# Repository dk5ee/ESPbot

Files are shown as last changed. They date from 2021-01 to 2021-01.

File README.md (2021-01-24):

# ESPbot
Another ESP32-cam based robot project

The repository contains:

* espcam - kicad footprint and library for ESP32-CAM
* TP5400 - kicad footprint and library for TP5400 and ESOP-8
* espbot - kicad project for a motherboard, clone of https://github.com/c3d2/C3-PR/tree/master/pcb

## Considerations TBD

* 0402 or 0805 or other footprints for resistors - make the pcb easier or make it smaller
* same for capacitors
* also capacitors: MLCC or electrolytics for the microfarad caps
* document the reset logic - does this work as intended?
* footprint for the inductor
* which usb socket?
* maximum pcb dimensions - more squarish or more longish?
* also pcb: where should the camera be located on the the assembly - more in the middle or on a side?
* also pcb: where should the antenna be located? on top, protruding over the edge of the motherboard?
* heat problem: the tp5400 and the esp32 will generate heat
* maybe power the motordriver directly from battery power, if the motor allows that
* consider alternatives to TP4500
* the inverters to save pins eliminate the possibility to do a motor brake

## Differences to C3-PR design

* made with kicad instead of easyeda
* instead of power from a USB powerbank this design uses a TP4500 power management chip
* instead of the dual NPN transistor every transistor is the same mosfet

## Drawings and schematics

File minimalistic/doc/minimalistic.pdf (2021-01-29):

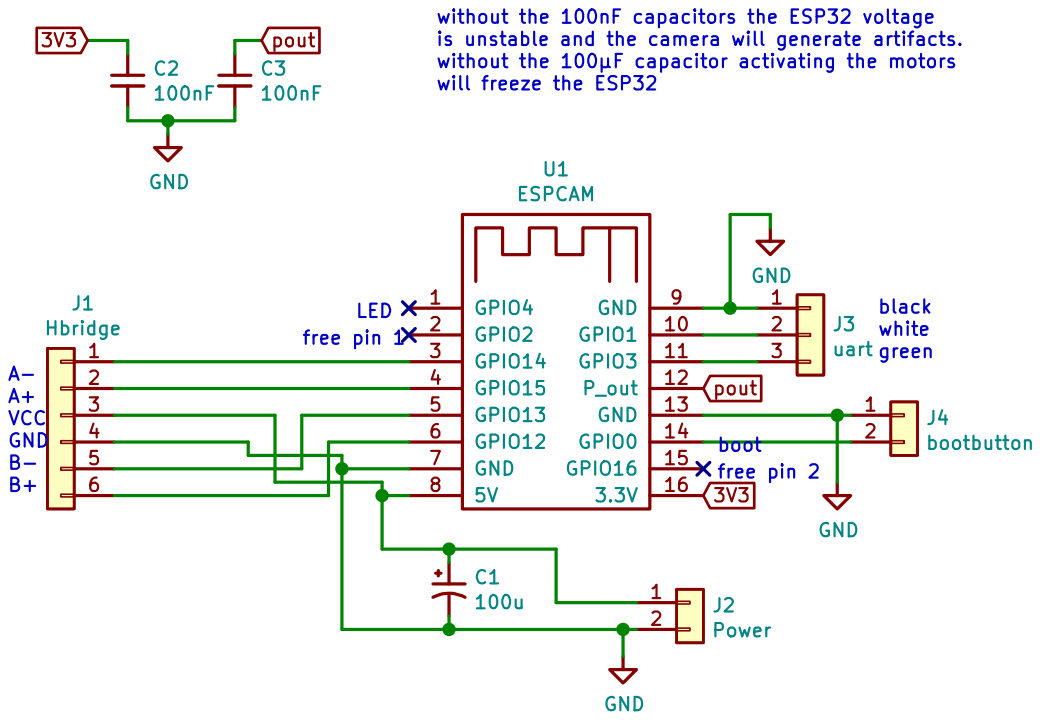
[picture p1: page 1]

is unstable and the camera will generate artifacts.
without the 100µF capacitor activating the motors will freeze the ESP32

Id: 1/1 Title: File: minimalistic.sch Sheet: / GND

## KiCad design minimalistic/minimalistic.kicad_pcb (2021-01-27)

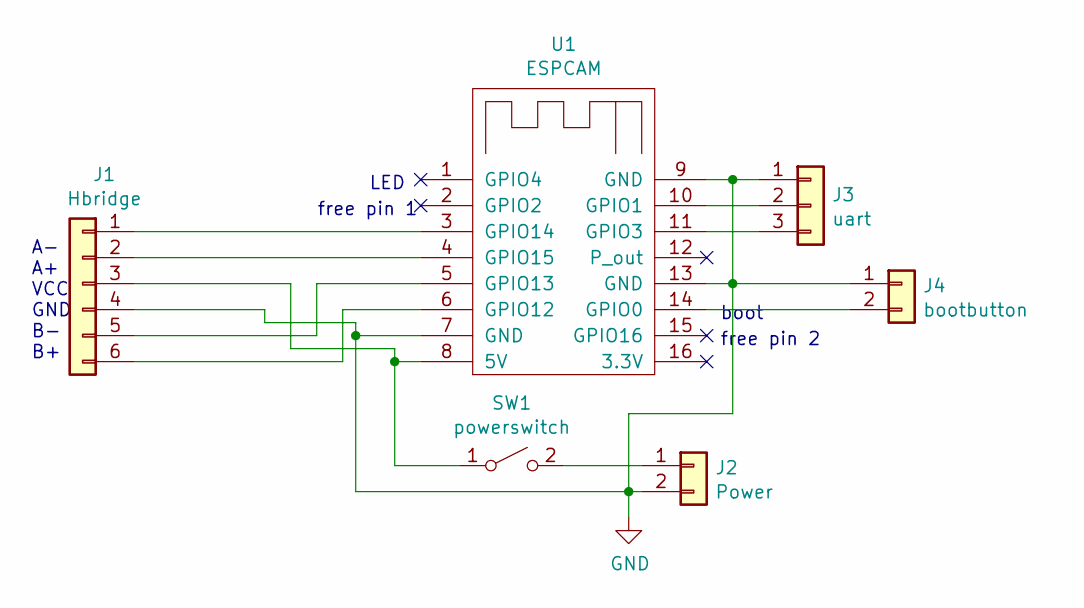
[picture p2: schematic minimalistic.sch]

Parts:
J1: Hbridge; PinHeader_1x06_P2.54mm_Vertical
J2: Power; JST_EH_B2B-EH-A_1x02_P2.50mm_Vertical
J3: uart; PinHeader_1x03_P2.54mm_Vertical
J4: bootbutton; PinHeader_1x02_P2.54mm_Vertical
SW1: powerswitch; PinHeader_1x02_P2.54mm_Vertical
U1: ESPCAM; ESPCAM_bottom

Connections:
GND: J1.4, J2.2, J3.1, J4.1, U1.7 (GND), U1.9 (GND), U1.13 (GND)
unnamed: J1.1, U1.3 (GPIO14)
unnamed: J1.2, U1.4 (GPIO15)
unnamed: J1.3, SW1.1 (A), U1.8 (5V)
unnamed: J1.5, U1.5 (GPIO13)
unnamed: J1.6, U1.6 (GPIO12)
unnamed: J2.1, SW1.2 (B)
unnamed: J3.2, U1.10 (GPIO1)
unnamed: J3.3, U1.11 (GPIO3)
unnamed: J4.2, U1.14 (GPIO0)

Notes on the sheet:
A- A+ VCC GND B- B+
LED
boot
free pin 1
free pin 2

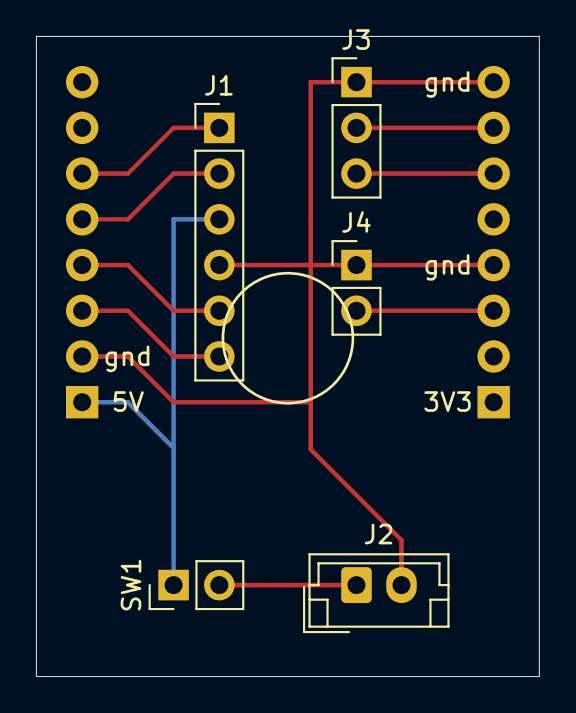
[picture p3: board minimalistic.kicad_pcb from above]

Board: 2 copper layers, 27.9 x 35.6 mm, 6 parts (0 on the bottom side), 10 nets.

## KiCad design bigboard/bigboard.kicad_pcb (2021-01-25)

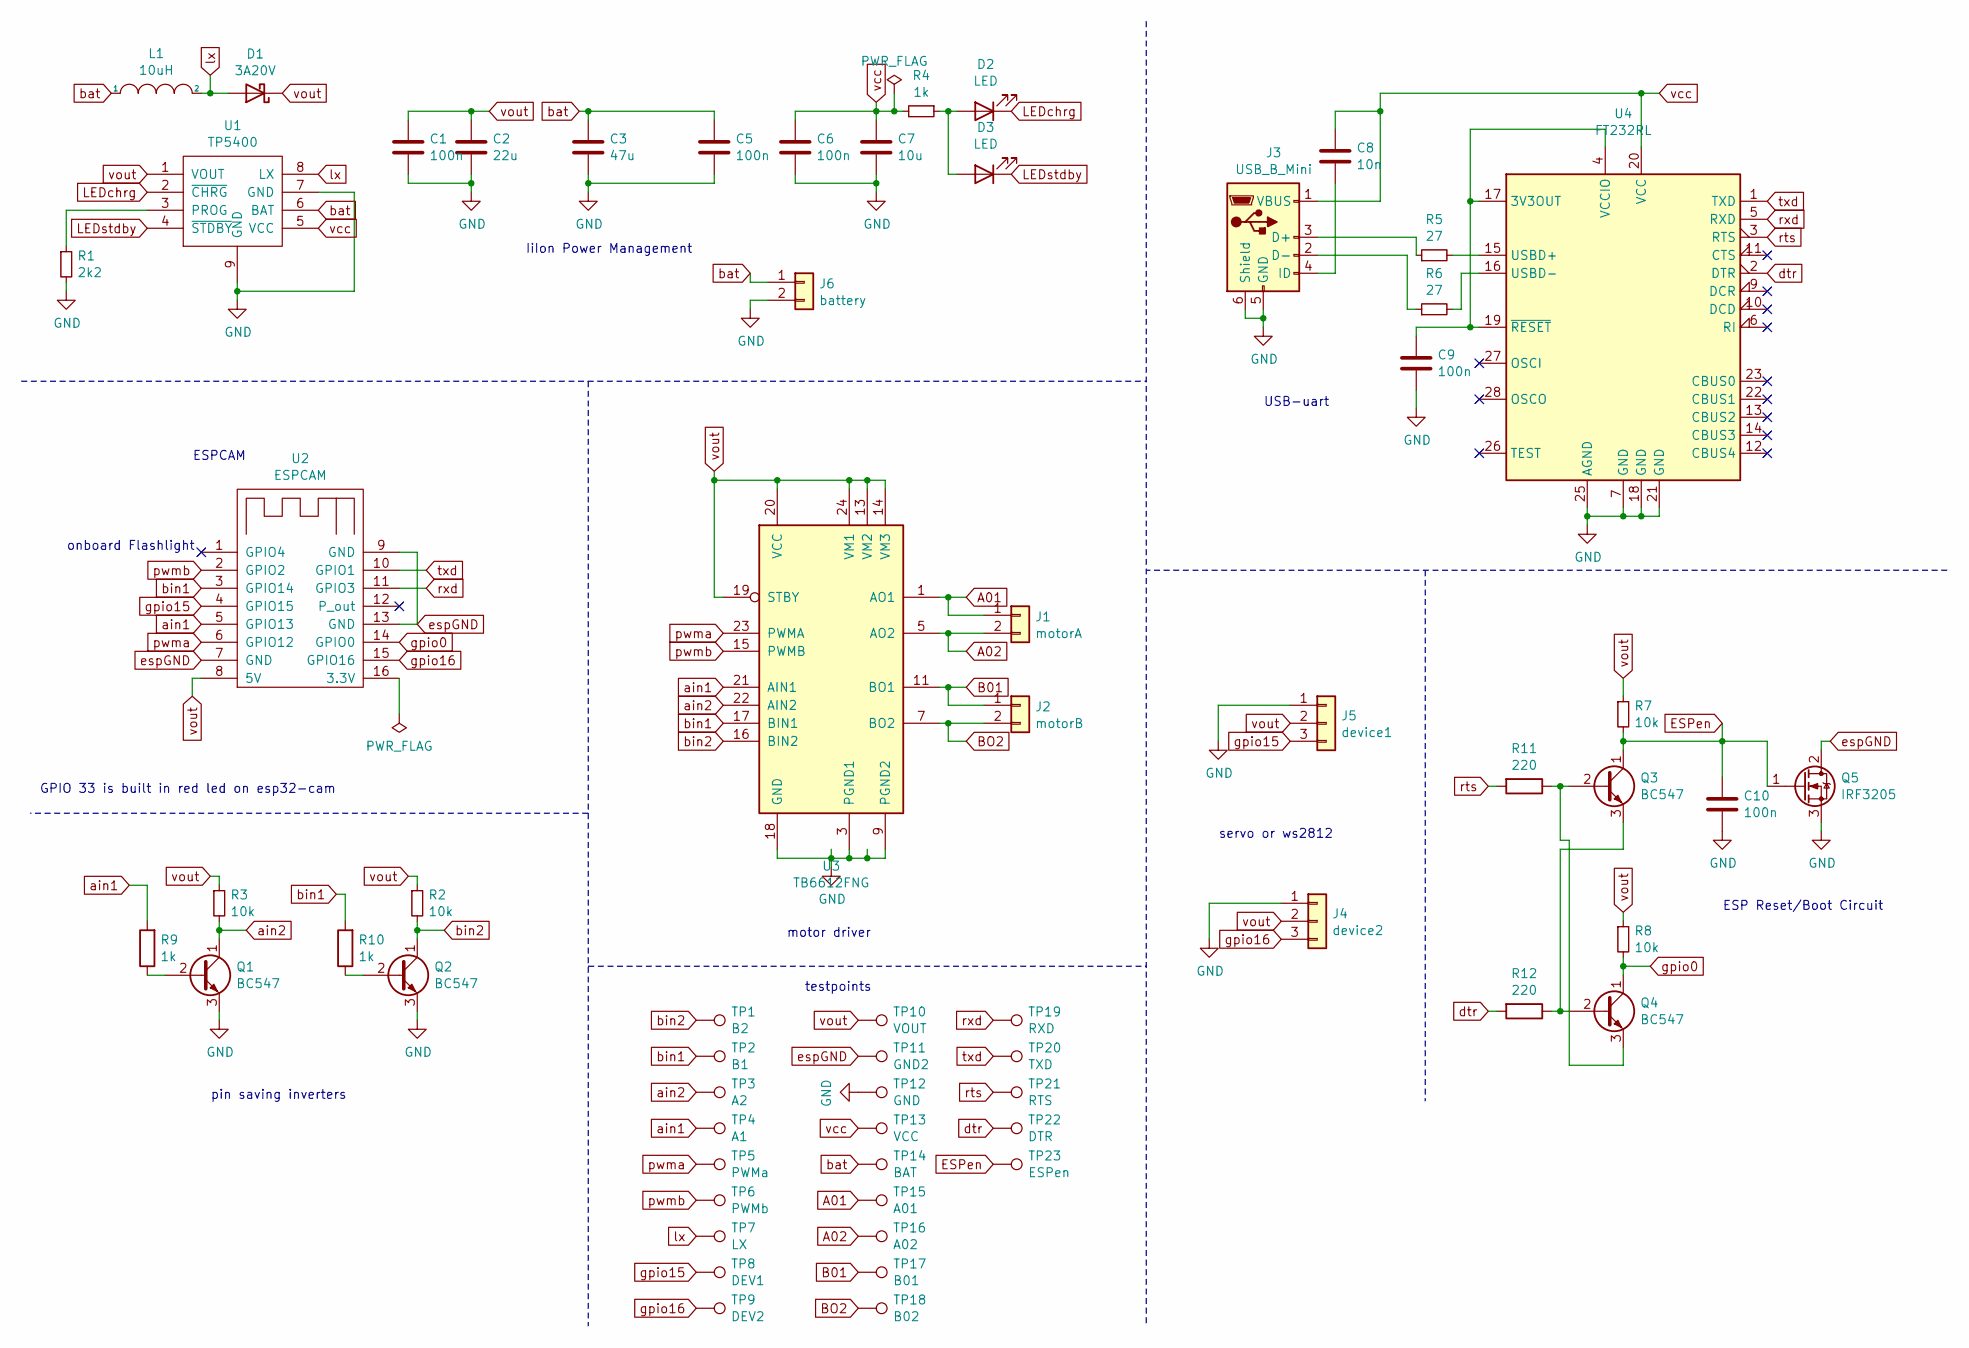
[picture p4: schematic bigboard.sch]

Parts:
C1, C5, C6, C9, C10: 100n; C_Disc_D3.0mm_W1.6mm_P2.50mm
C2: 22u; CP_Radial_D10.0mm_P2.50mm_P5.00mm
C3: 47u; CP_Radial_D10.0mm_P2.50mm_P5.00mm
C7: 10u; CP_Radial_D10.0mm_P2.50mm_P5.00mm
C8: 10n; C_Disc_D4.3mm_W1.9mm_P5.00mm
D1: 3A20V; D_A-405_P7.62mm_Horizontal
D2, D3: LED; LED_D3.0mm
J1: motorA; PinHeader_1x02_P2.54mm_Vertical
J2: motorB; PinHeader_1x02_P2.54mm_Vertical
J3: USB_B_Mini; USB_Micro-B_Amphenol_10118194_Horizontal
J4: device2; PinHeader_1x03_P2.54mm_Vertical
J5: device1; PinHeader_1x03_P2.54mm_Vertical
J6: battery; PinHeader_1x02_P2.54mm_Vertical
L1: 10uH; L_Toroid_Vertical_L10.0mm_W5.0mm_P5.08mm
Q1, Q2, Q3, Q4: BC547; TO-92_Inline
Q5: IRF3205; TO-220F-3_Horizontal_TabDown
R1: 2k2; R_Axial_DIN0204_L3.6mm_D1.6mm_P5.08mm_Horizontal
R2, R3, R7, R8: 10k; R_Axial_DIN0204_L3.6mm_D1.6mm_P5.08mm_Horizontal
R4, R9, R10: 1k; R_Axial_DIN0204_L3.6mm_D1.6mm_P5.08mm_Horizontal
R5, R6: 27; R_Axial_DIN0204_L3.6mm_D1.6mm_P5.08mm_Horizontal
R11, R12: 220; R_Axial_DIN0204_L3.6mm_D1.6mm_P5.08mm_Horizontal
TP1: B2; TestPoint_Bridge_Pitch2.54mm_Drill0.7mm
TP2: B1; TestPoint_Bridge_Pitch2.54mm_Drill0.7mm
TP3: A2; TestPoint_Bridge_Pitch2.54mm_Drill0.7mm
TP4: A1; TestPoint_Bridge_Pitch2.54mm_Drill0.7mm
TP5: PWMa; TestPoint_Bridge_Pitch2.54mm_Drill0.7mm
TP6: PWMb; TestPoint_Bridge_Pitch2.54mm_Drill0.7mm
TP7: LX; TestPoint_Bridge_Pitch2.54mm_Drill0.7mm
TP8: DEV1; TestPoint_Bridge_Pitch2.54mm_Drill0.7mm
TP9: DEV2; TestPoint_Bridge_Pitch2.54mm_Drill0.7mm
TP10: VOUT; TestPoint_Bridge_Pitch2.54mm_Drill0.7mm
TP11: GND2; TestPoint_Bridge_Pitch2.54mm_Drill0.7mm
TP12: GND; TestPoint_Bridge_Pitch2.54mm_Drill0.7mm
TP13: VCC; TestPoint_Bridge_Pitch2.54mm_Drill0.7mm
TP14: BAT; TestPoint_Bridge_Pitch2.54mm_Drill0.7mm
TP15: A01; TestPoint_Bridge_Pitch2.54mm_Drill0.7mm
TP16: A02; TestPoint_Bridge_Pitch2.54mm_Drill0.7mm
TP17: B01; TestPoint_Bridge_Pitch2.54mm_Drill0.7mm
TP18: B02; TestPoint_Bridge_Pitch2.54mm_Drill0.7mm
TP19: RXD; TestPoint_Bridge_Pitch2.54mm_Drill0.7mm
TP20: TXD; TestPoint_Bridge_Pitch2.54mm_Drill0.7mm
TP21: RTS; TestPoint_Bridge_Pitch2.54mm_Drill0.7mm
TP22: DTR; TestPoint_Bridge_Pitch2.54mm_Drill0.7mm
TP23: ESPen; TestPoint_Bridge_Pitch2.54mm_Drill0.7mm
U1: TP5400; ESOP8-F.Cu-only
U2: ESPCAM; ESPCAM_bottom
U3: TB6612FNG; SSOP-24_5.3x8.2mm_P0.65mm
U4: FT232RL; SSOP-28_5.3x10.2mm_P0.65mm

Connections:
A01: J1.1, TP15.1, U3.1 (AO1), U3.2 (AO1)
A02: J1.2, TP16.1, U3.5 (AO2), U3.6 (AO2)
B01: J2.1, TP17.1, U3.11 (BO1), U3.12 (BO1)
BO2: J2.2, TP18.1, U3.7 (BO2), U3.8 (BO2)
ESPen: C10.1, Q3.1 (C), Q5.1 (G), R7.2, TP23.1
GND: C1.2, C2.2, C3.2, C5.2, C6.2, C7.2, C9.2, C10.2, J3.5 (GND), J3.6 (Shield), J4.1, J5.1, J6.2, Q1.3 (E), Q2.3 (E), Q5.3 (S), R1.2, TP12.1, U1.7 (GND), U1.9 (GND), U3.3 (PGND1), U3.4 (PGND1), U3.9 (PGND2), U3.10 (PGND2), U3.18 (GND), U4.7 (GND), U4.18 (GND), U4.21 (GND), U4.25 (AGND)
LEDchrg: D2.1 (K), U1.2 (~CHRG)
LEDstdby: D3.1 (K), U1.4 (~STDBY)
unnamed: C8.2, J3.4 (ID)
unnamed: C9.1, U4.4 (VCCIO), U4.17 (3V3OUT), U4.19 (~RESET~)
unnamed: D2.2 (A), D3.2 (A), R4.1
unnamed: J3.2 (D-), R6.1
unnamed: J3.3 (D+), R5.1
unnamed: Q1.2 (B), R9.1
unnamed: Q2.2 (B), R10.1
unnamed: Q3.2 (B), Q4.3 (E), R11.1
unnamed: Q3.3 (E), Q4.2 (B), R12.1
unnamed: R1.1, U1.3 (PROG)
unnamed: R5.2, U4.15 (USBD+)
unnamed: R6.2, U4.16 (USBD-)
ain1: R9.2, TP4.1, U2.5 (GPIO13), U3.21 (AIN1)
ain2: Q1.1 (C), R3.2, TP3.1, U3.22 (AIN2)
bat: C3.1, C5.1, J6.1, L1.1, TP14.1, U1.6 (BAT)
bin1: R10.2, TP2.1, U2.3 (GPIO14), U3.17 (BIN1)
bin2: Q2.1 (C), R2.2, TP1.1, U3.16 (BIN2)
dtr: R12.2, TP22.1, U4.2 (DTR)
espGND: Q5.2 (D), TP11.1, U2.7 (GND), U2.9 (GND), U2.13 (GND)
gpio0: Q4.1 (C), R8.2, U2.14 (GPIO0)
gpio15: J5.3, TP8.1, U2.4 (GPIO15)
gpio16: J4.3, TP9.1, U2.15 (GPIO16)
lx: D1.2 (A), L1.2, TP7.1, U1.8 (LX)
pwma: TP5.1, U2.6 (GPIO12), U3.23 (PWMA)
pwmb: TP6.1, U2.2 (GPIO2), U3.15 (PWMB)
rts: R11.2, TP21.1, U4.3 (RTS)
rxd: TP19.1, U2.11 (GPIO3), U4.5 (RXD)
txd: TP20.1, U2.10 (GPIO1), U4.1 (TXD)
vcc: C6.1, C7.1, C8.1, J3.1 (VBUS), R4.2, TP13.1, U1.5 (VCC), U4.20 (VCC)
vout: C1.1, C2.1, D1.1 (K), J4.2, J5.2, R2.1, R3.1, R7.1, R8.1, TP10.1, U1.1 (VOUT), U2.8 (5V), U3.13 (VM2), U3.14 (VM3), U3.19 (STBY), U3.20 (VCC), U3.24 (VM1)

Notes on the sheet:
IiIon Power Management
USB-uart
motor driver
ESPCAM
ESP Reset/Boot Circuit
onboard Flashlight
servo or ws2812
pin saving inverters
GPIO 33 is built in red led on esp32-cam
testpoints

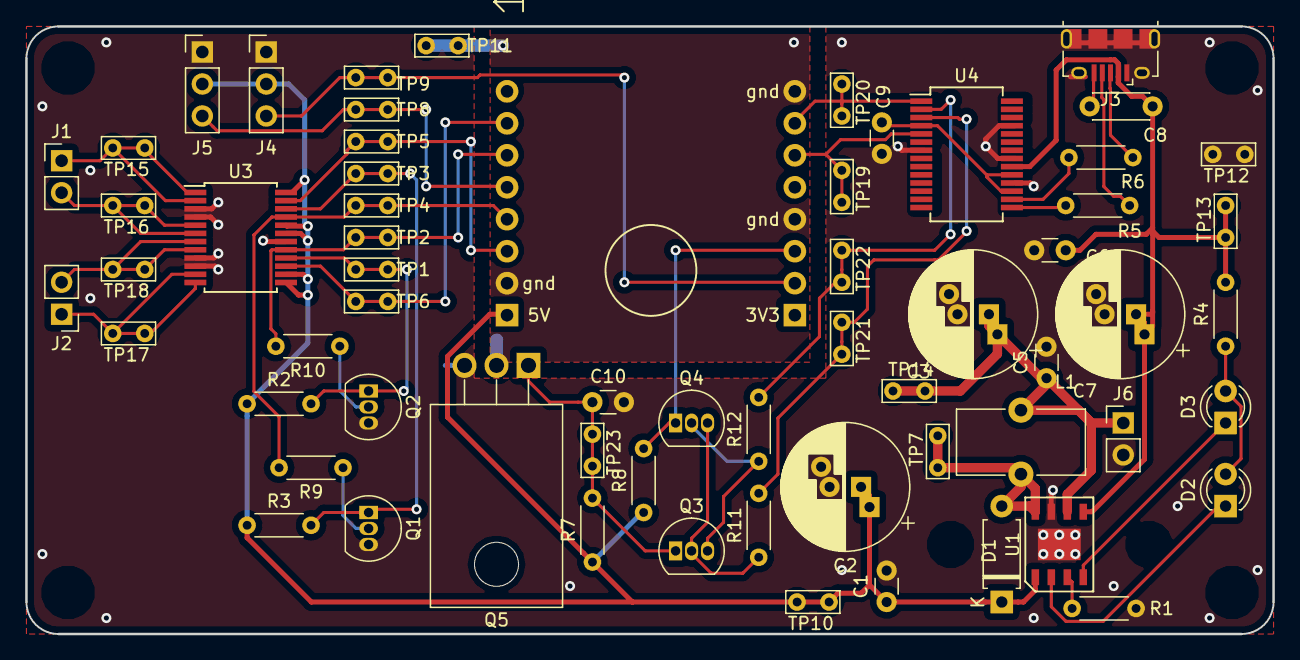
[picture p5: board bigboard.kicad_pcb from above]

Board: 2 copper layers, 99.1 x 48.3 mm, 63 parts (0 on the bottom side), 38 nets.

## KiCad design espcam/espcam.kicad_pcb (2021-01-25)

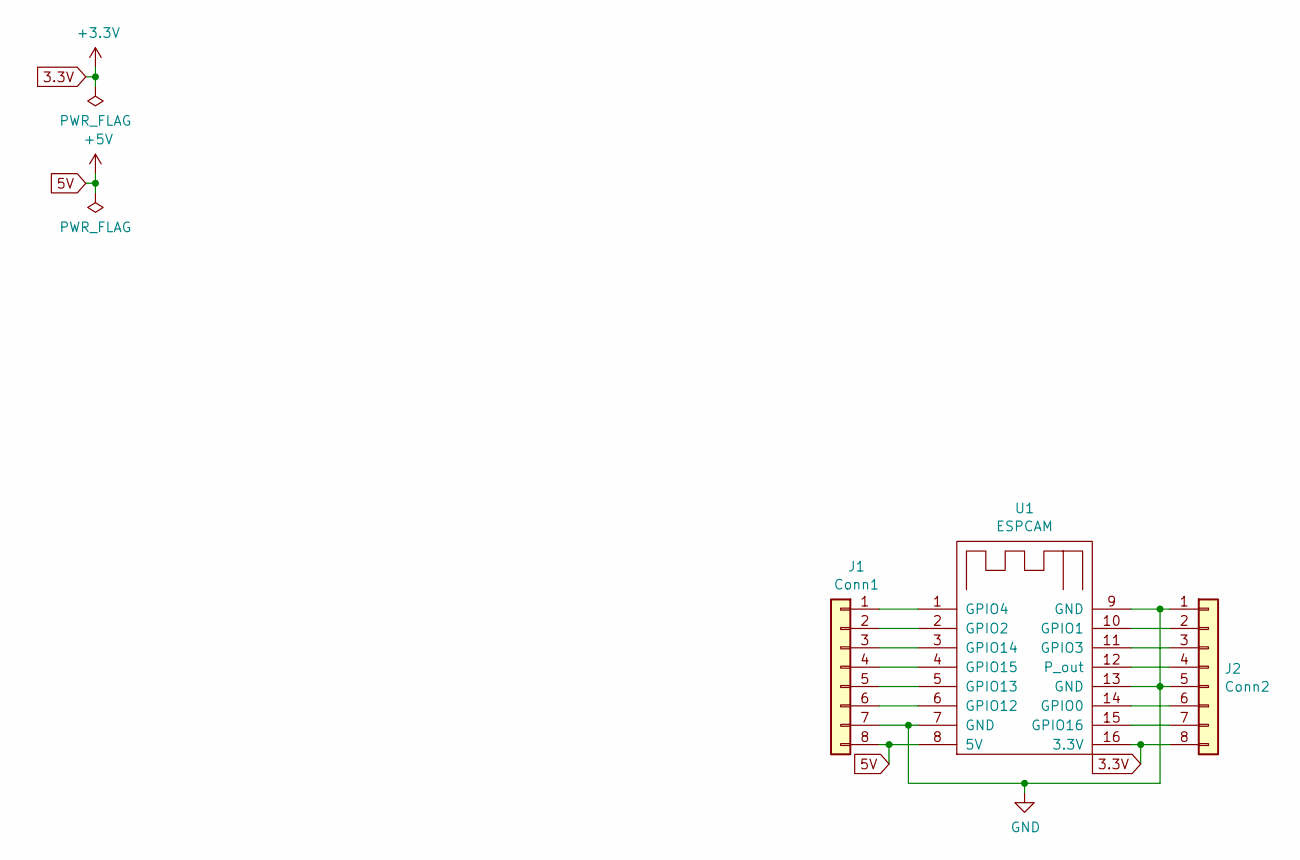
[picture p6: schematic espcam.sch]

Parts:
J1: Conn1; PinSocket_1x08_P2.54mm_Vertical
J2: Conn2; PinSocket_1x08_P2.54mm_Vertical
U1: ESPCAM; ESPCAM_bottom

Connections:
3.3V: J2.8, U1.16 (3.3V)
5V: J1.8, U1.8 (5V)
GND: J1.7, J2.1, J2.5, U1.7 (GND), U1.9 (GND), U1.13 (GND)
unnamed: J1.1, U1.1 (GPIO4)
unnamed: J1.2, U1.2 (GPIO2)
unnamed: J1.3, U1.3 (GPIO14)
unnamed: J1.4, U1.4 (GPIO15)
unnamed: J1.5, U1.5 (GPIO13)
unnamed: J1.6, U1.6 (GPIO12)
unnamed: J2.2, U1.10 (GPIO1)
unnamed: J2.3, U1.11 (GPIO3)
unnamed: J2.4, U1.12 (P_out)
unnamed: J2.6, U1.14 (GPIO0)
unnamed: J2.7, U1.15 (GPIO16)

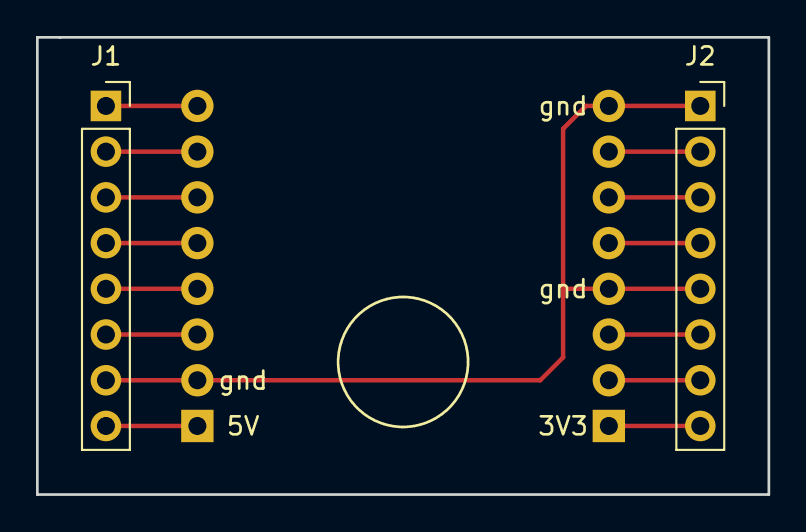
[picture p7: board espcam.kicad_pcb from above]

Board: 2 copper layers, 40.6 x 25.4 mm, 3 parts (0 on the bottom side), 14 nets.

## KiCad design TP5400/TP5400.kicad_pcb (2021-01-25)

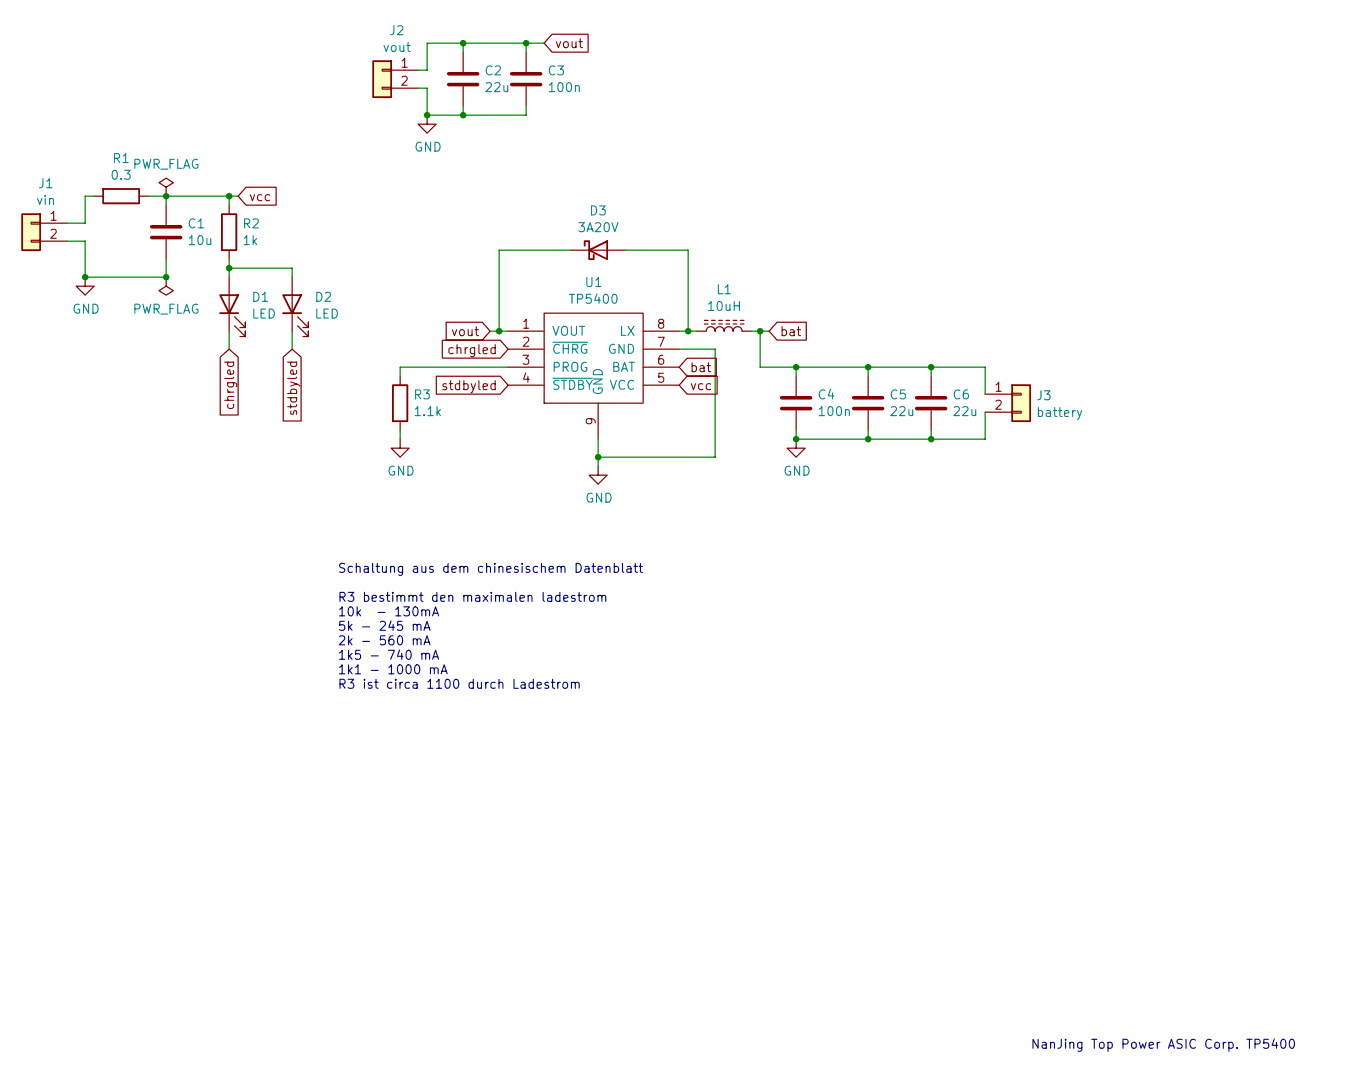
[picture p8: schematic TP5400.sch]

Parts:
C1: 10u; C_0805_2012Metric_Pad1.15x1.40mm_HandSolder
C2, C5, C6: 22u; C_0805_2012Metric_Pad1.15x1.40mm_HandSolder
C3, C4: 100n; C_0805_2012Metric_Pad1.15x1.40mm_HandSolder
D1, D2: LED; LED_0805_2012Metric_Pad1.15x1.40mm_HandSolder
D3: 3A20V; D_0805_2012Metric_Pad1.15x1.40mm_HandSolder
J1: vin; PinSocket_1x02_P2.54mm_Vertical
J2: vout; PinSocket_1x02_P2.54mm_Vertical
J3: battery; PinSocket_1x02_P2.54mm_Vertical
L1: 10uH; L_Wuerth_WE-PD-Typ-M-Typ-S_Handsoldering
R1: 0.3; R_0805_2012Metric_Pad1.15x1.40mm_HandSolder
R2: 1k; R_0805_2012Metric_Pad1.15x1.40mm_HandSolder
R3: 1.1k; R_0805_2012Metric_Pad1.15x1.40mm_HandSolder
U1: TP5400; ESOP8-F.Cu-only

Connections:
GND: C1.2, C2.2, C3.2, C4.2, C5.2, C6.2, J1.2, J2.2, J3.2, R3.2, U1.7 (GND), U1.9 (GND)
unnamed: D1.2 (A), D2.2 (A), R2.2
unnamed: D3.2 (A), L1.1, U1.8 (LX)
unnamed: J1.1, R1.2
unnamed: R3.1, U1.3 (PROG)
bat: C4.1, C5.1, C6.1, J3.1, L1.2, U1.6 (BAT)
chrgled: D1.1 (K), U1.2 (~CHRG)
stdbyled: D2.1 (K), U1.4 (~STDBY)
vcc: C1.1, R1.1, R2.1, U1.5 (VCC)
vout: C2.1, C3.1, D3.1 (K), J2.1, U1.1 (VOUT)

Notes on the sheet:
Schaltung aus dem chinesischem Datenblatt R3 bestimmt den maximalen ladestrom 10k - 130mA 5k - 245 mA 2k - 560 mA 1k5 - 740 mA 1k1 - 1000 mA R3 ist circa 1100 durch Ladestrom
NanJing Top Power ASIC Corp. TP5400

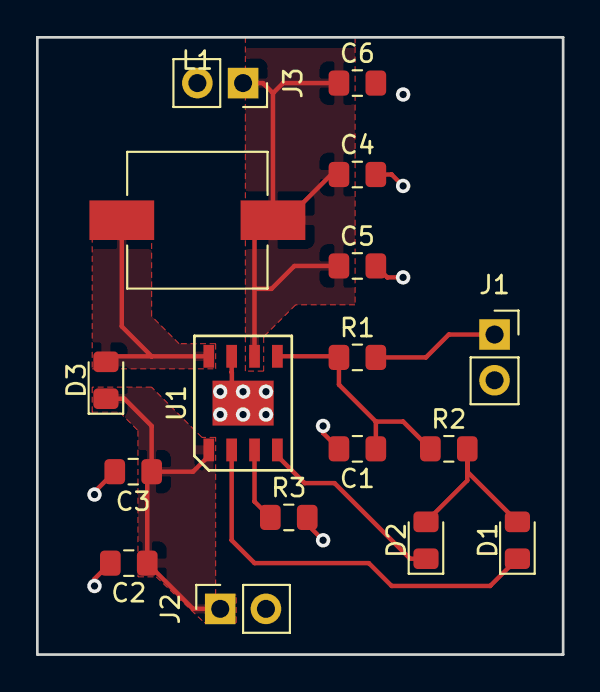
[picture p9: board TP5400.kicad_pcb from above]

Board: 2 copper layers, 29.2 x 34.3 mm, 17 parts (0 on the bottom side), 10 nets.

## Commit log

2021-01-24 fix and design of big board
    [bigboard.kicad_pcb, bigboard.sch]
2021-01-25 Fix Footprints for kicad 5.1.8
    thanks to tobi for the tip how to install a newer
    kicad on debian: there is a newer version in
    debian-packports.
    fixed the libraries and footprints, and changed
    the path to relative ones.
    [TP5400.kicad_pcb, TP5400.sch, bigboard.kicad_pcb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]
2021-01-27 minimalistic pcb for prototyping
    [minimalistic.kicad_pcb, minimalistic.sch]
2021-01-29 working minimalistic board
    [minimalistic.sch]
